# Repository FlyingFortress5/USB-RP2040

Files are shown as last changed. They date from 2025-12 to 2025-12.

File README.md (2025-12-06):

# USB-RP2040-DEVB
A RP2040 powered mini dev board. It has 2 GPIO pins, and is intended mainly for scripted HID emulation.

## Features

 - Light BOM
 - extra small size
 - male usb-c plug

## BOM

| Footprint | Designation | Quantity | | |
|---|---|---|---|---|
| USB_C_Plug_Molex_105444 | USB_C_Plug_USB2.0 | 1 | | |
| C_0402_1005Metric | 0.1uF | 10 | | |
| Winbond_USON-8-1EP_3x2mm_P0.5mm_EP0.2x1.6mm | W25Q16JVZPIQ_TR | 1 | | |
| SOT95P237X112-3N | MCP1700T-3302E_TT | 1 | | |
| SW_Push_1P1T-SH_NO_CK_KMR2xxG | SW_Push | 1 | | |
| PinHeader_1x03_P1.00mm_Vertical | Conn_01x03 | 1 | | |
| Crystal_SMD_3225-4Pin_3.2x2.5mm | 12 MHz | 1 | | |
| QFN-56-1EP_7x7mm_P0.4mm_EP3.2x3.2mm | RP2040 | 1 | | |
| R_0402_1005Metric | 10K | 1 | | |
| R_0402_1005Metric | 1K | 2 | | |
| R_0402_1005Metric | 27 | 2 | | |
| R_0402_1005Metric | 5.1K | 2 | | |
| C_0402_1005Metric | 15pF | 2 | | |
| C_0603_1608Metric_Pad1.08x0.95mm_HandSolder | 10uF | 2 | | |
| C_0402_1005Metric | 1uF | 2 | | |

## Case
A simple friction fit case

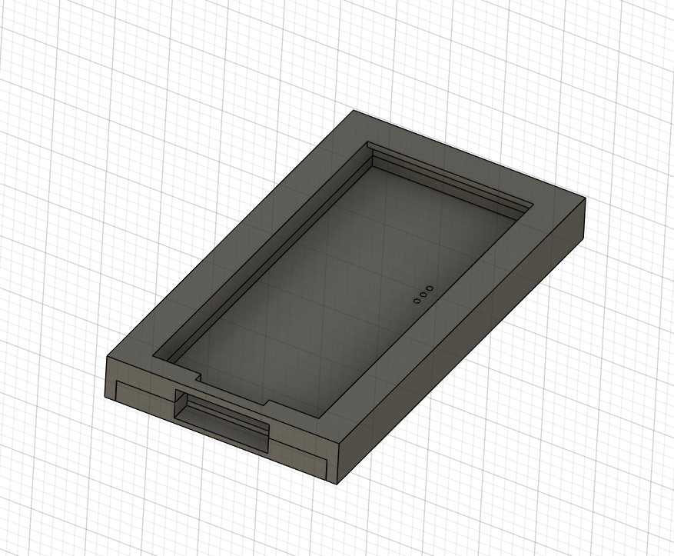
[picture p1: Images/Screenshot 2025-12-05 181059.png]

## Images

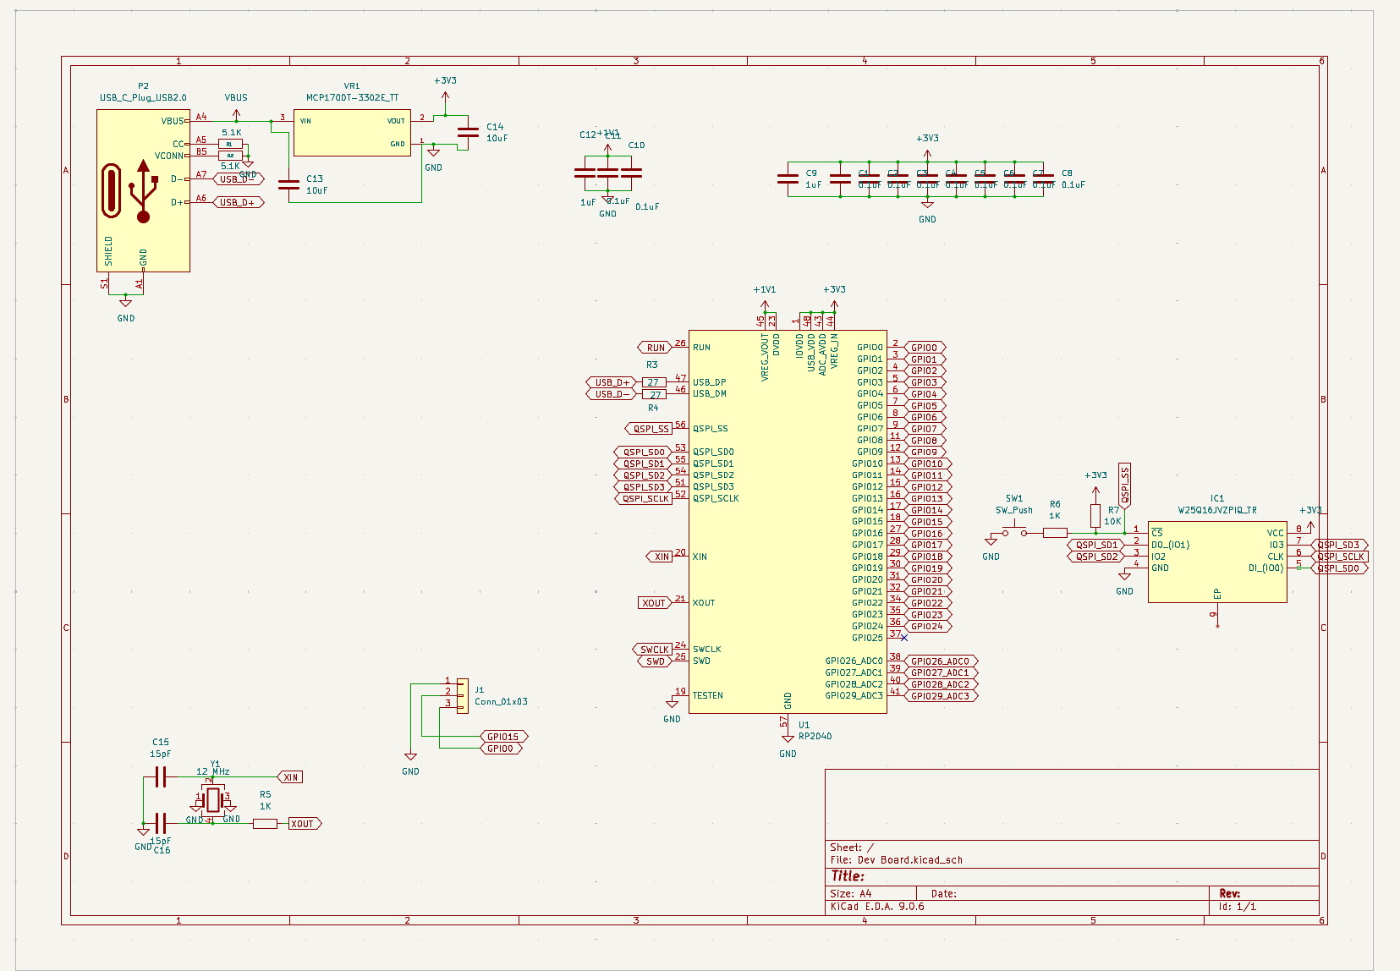
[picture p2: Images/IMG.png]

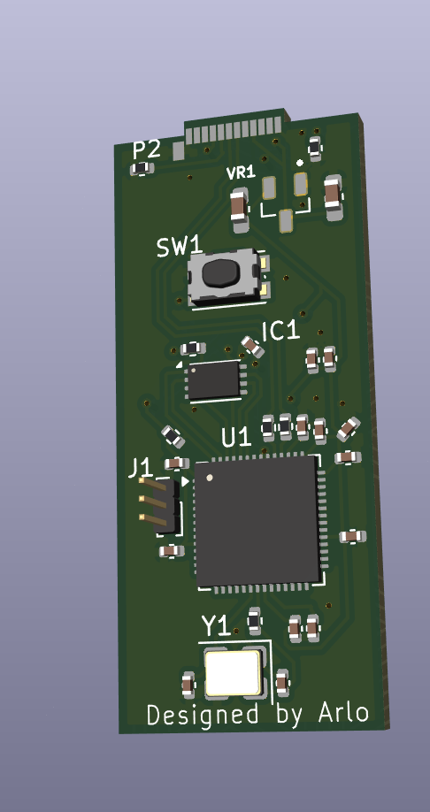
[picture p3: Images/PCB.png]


## Pinout

The pins on the header from top to bottom are:
 - GPIO0
 - GPIO15
 - GND
 The button enters BOOTSEL

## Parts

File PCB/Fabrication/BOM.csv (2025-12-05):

Id | Designator | Footprint | Quantity | Designation | Supplier and ref
1 | P2 | USB_C_Plug_Molex_105444 | 1 | USB_C_Plug_USB2.0
2 | C10,C11,C8,C7,C6,C5,C4,C3,C2,C1 | C_0402_1005Metric | 10 | 0.1uF
3 | IC1 | Winbond_USON-8-1EP_3x2mm_P0.5mm_EP0.2x1.6mm | 1 | W25Q16JVZPIQ_TR
4 | VR1 | SOT95P237X112-3N | 1 | MCP1700T-3302E_TT
5 | SW1 | SW_Push_1P1T-SH_NO_CK_KMR2xxG | 1 | SW_Push
6 | J1 | PinHeader_1x03_P1.00mm_Vertical | 1 | Conn_01x03
7 | Y1 | Crystal_SMD_3225-4Pin_3.2x2.5mm | 1 | 12 MHz
8 | U1 | QFN-56-1EP_7x7mm_P0.4mm_EP3.2x3.2mm | 1 | RP2040
9 | R7 | R_0402_1005Metric | 1 | 10K
10 | R6,R5 | R_0402_1005Metric | 2 | 1K
11 | R4,R3 | R_0402_1005Metric | 2 | 27
12 | R2,R1 | R_0402_1005Metric | 2 | 5.1K
13 | C16,C15 | C_0402_1005Metric | 2 | 15pF
14 | C14,C13 | C_0603_1608Metric_Pad1.08x0.95mm_HandSolder | 2 | 10uF
15 | C12,C9 | C_0402_1005Metric | 2 | 1uF

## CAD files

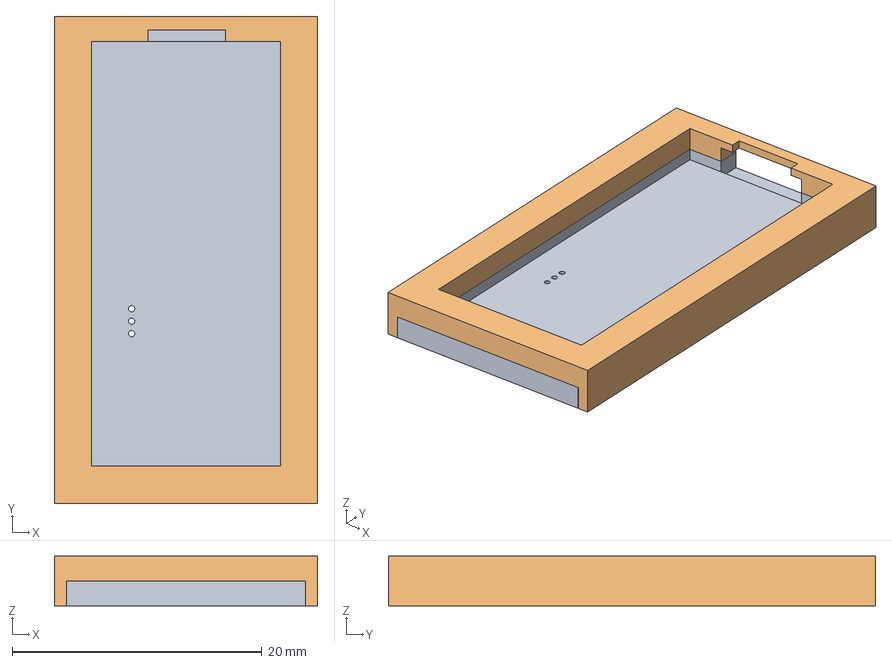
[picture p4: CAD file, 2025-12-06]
Case/Case.step
21.1 x 39.0 x 4.00 mm

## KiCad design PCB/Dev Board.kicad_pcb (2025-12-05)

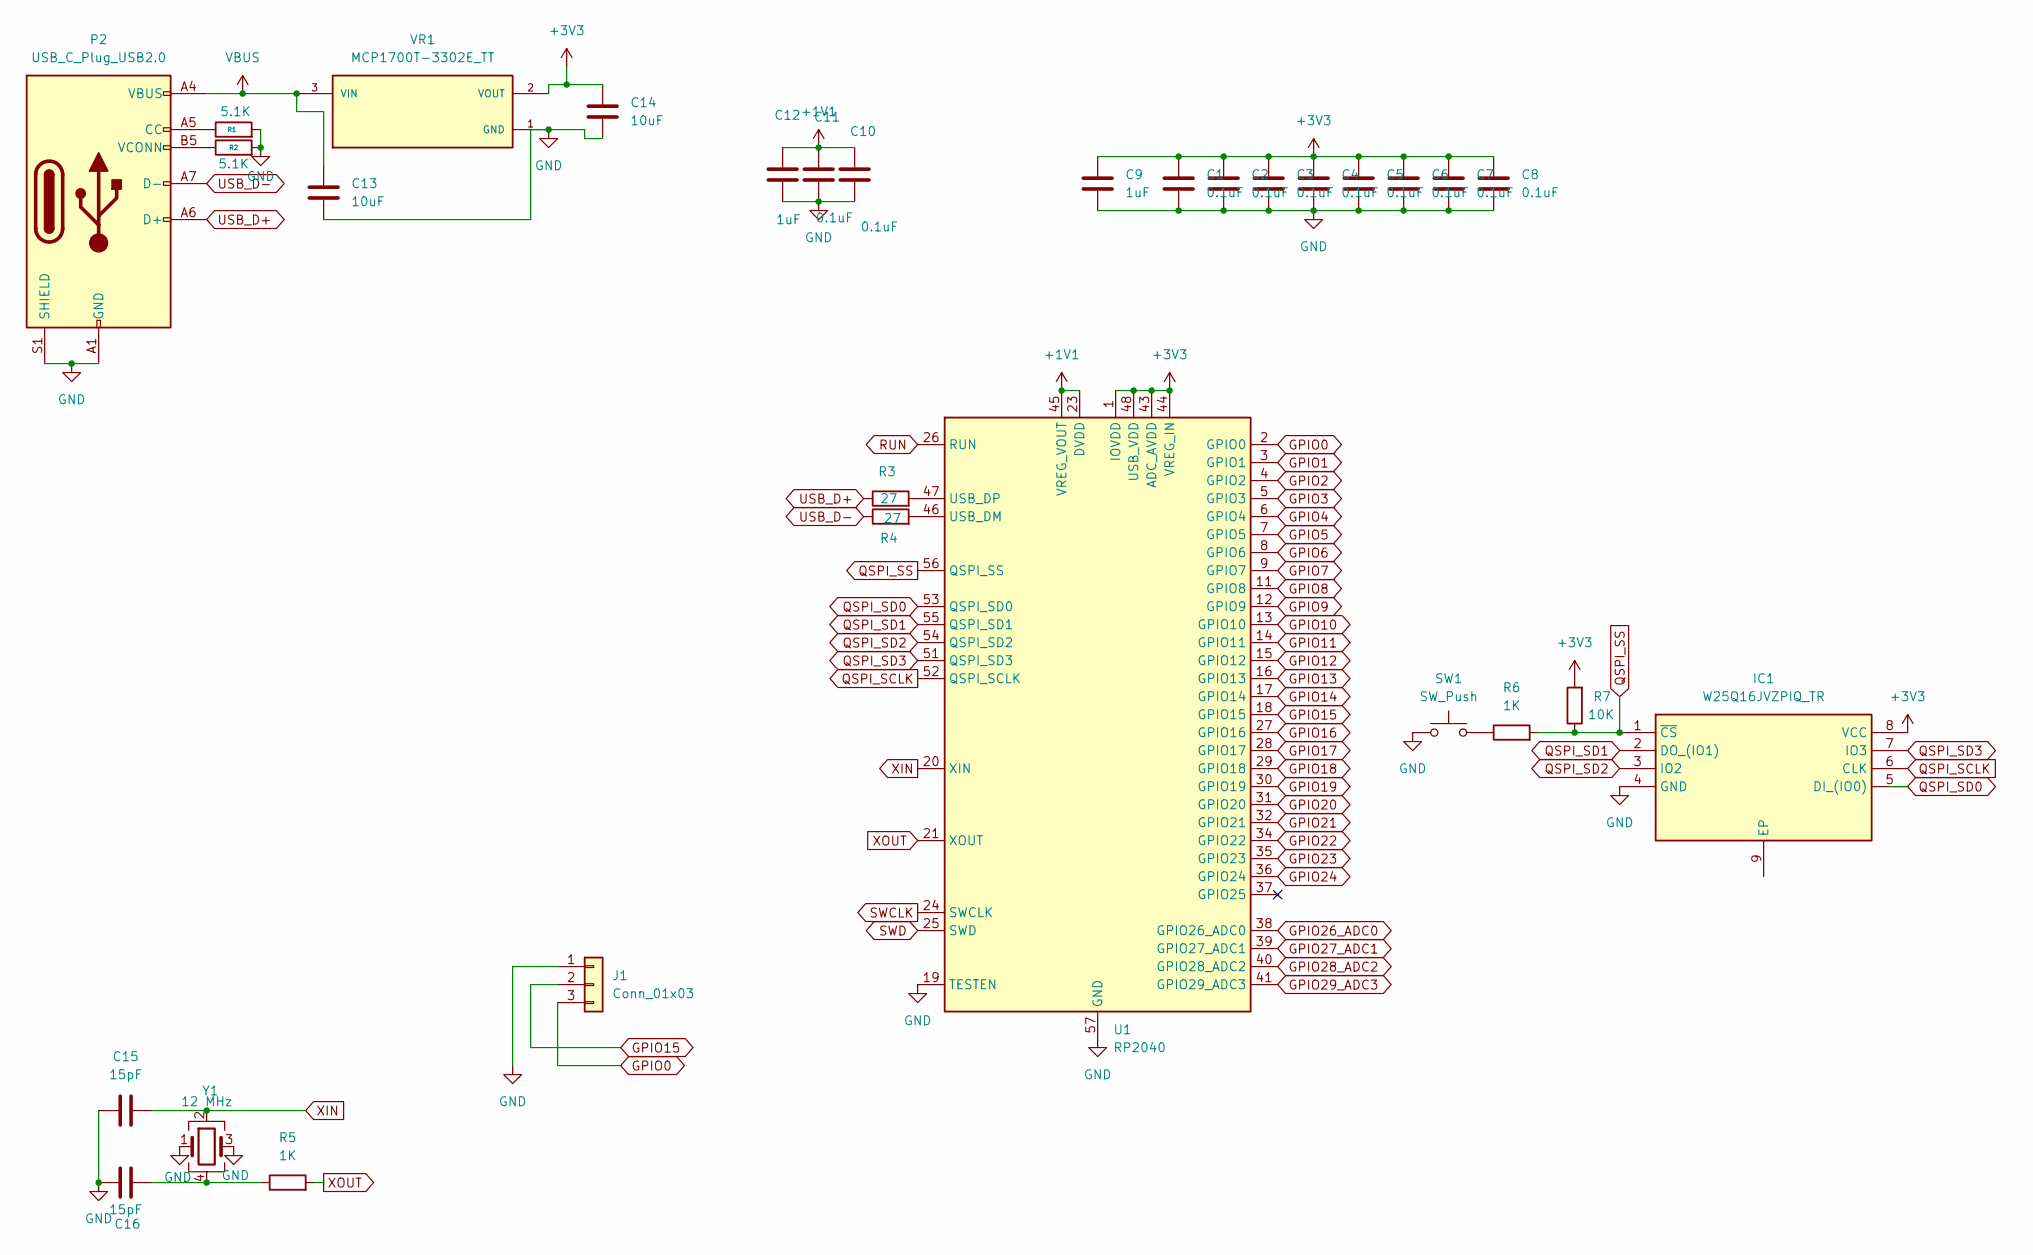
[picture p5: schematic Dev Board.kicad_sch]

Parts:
C1, C2, C3, C4, C5, C6, C7, C8, C10, C11: 0.1uF; C_0402_1005Metric
C9, C12: 1uF; C_0402_1005Metric
C13, C14: 10uF; C_0603_1608Metric_Pad1.08x0.95mm_HandSolder
C15, C16: 15pF; C_0402_1005Metric
IC1: W25Q16JVZPIQ_TR; Winbond_USON-8-1EP_3x2mm_P0.5mm_EP0.2x1.6mm; Manufacturer_Part_Number W25Q16JVZPIQ TR
J1: Conn_01x03; PinHeader_1x03_P1.00mm_Vertical
P2: USB_C_Plug_USB2.0; USB_C_Plug_Molex_105444
R1, R2: 5.1K; R_0402_1005Metric
R3, R4: 27; R_0402_1005Metric
R5, R6: 1K; R_0402_1005Metric
R7: 10K; R_0402_1005Metric
SW1: SW_Push; SW_Push_1P1T-SH_NO_CK_KMR2xxG
U1: RP2040; QFN-56-1EP_7x7mm_P0.4mm_EP3.2x3.2mm
VR1: MCP1700T-3302E_TT; SOT95P237X112-3N; PARTREV E
Y1: 12 MHz; Crystal_SMD_3225-4Pin_3.2x2.5mm

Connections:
+1V1: C10.1, C11.1, C12.1, U1.23 (DVDD), U1.45 (VREG_VOUT), U1.50 (DVDD)
+3V3: C1.1, C2.1, C3.1, C4.1, C5.1, C6.1, C7.1, C8.1, C9.1, C14.1, IC1.8 (VCC), R7.2, U1.1 (IOVDD), U1.10 (IOVDD), U1.22 (IOVDD), U1.33 (IOVDD), U1.42 (IOVDD), U1.43 (ADC_AVDD), U1.44 (VREG_IN), U1.48 (USB_VDD), U1.49 (IOVDD), VR1.2 (VOUT)
GND: C1.2, C2.2, C3.2, C4.2, C5.2, C6.2, C7.2, C8.2, C9.2, C10.2, C11.2, C12.2, C13.2, C14.2, C15.1, C16.1, IC1.4 (GND), J1.1, P2.A1 (GND), P2.A12 (GND), P2.B1 (GND), P2.B12 (GND), P2.S1 (SHIELD), R1.2, R2.2, SW1.1, U1.19 (TESTEN), U1.57 (GND), VR1.1 (GND), Y1.1, Y1.3
GPIO0: J1.3, U1.2 (GPIO0)
GPIO1: U1.3 (GPIO1)
GPIO2: U1.4 (GPIO2)
GPIO3: U1.5 (GPIO3)
GPIO4: U1.6 (GPIO4)
GPIO5: U1.7 (GPIO5)
GPIO6: U1.8 (GPIO6)
GPIO7: U1.9 (GPIO7)
GPIO8: U1.11 (GPIO8)
GPIO9: U1.12 (GPIO9)
GPIO10: U1.13 (GPIO10)
GPIO11: U1.14 (GPIO11)
GPIO12: U1.15 (GPIO12)
GPIO13: U1.16 (GPIO13)
GPIO14: U1.17 (GPIO14)
GPIO15: J1.2, U1.18 (GPIO15)
GPIO16: U1.27 (GPIO16)
GPIO17: U1.28 (GPIO17)
GPIO18: U1.29 (GPIO18)
GPIO19: U1.30 (GPIO19)
GPIO20: U1.31 (GPIO20)
GPIO21: U1.32 (GPIO21)
GPIO22: U1.34 (GPIO22)
GPIO23: U1.35 (GPIO23)
GPIO24: U1.36 (GPIO24)
GPIO26_ADC0: U1.38 (GPIO26_ADC0)
GPIO27_ADC1: U1.39 (GPIO27_ADC1)
GPIO28_ADC2: U1.40 (GPIO28_ADC2)
GPIO29_ADC3: U1.41 (GPIO29_ADC3)
unnamed: C16.2, R5.1, Y1.4
unnamed: P2.A5 (CC), R1.1
unnamed: P2.B5 (VCONN), R2.1
unnamed: R6.1, SW1.2
unnamed: R4.2, U1.46 (USB_DM)
unnamed: R3.2, U1.47 (USB_DP)
QSPI_SCLK: IC1.6 (CLK), U1.52 (QSPI_SCLK)
QSPI_SD0: IC1.5 (DI_(IO0)), U1.53 (QSPI_SD0)
QSPI_SD1: IC1.2 (DO_(IO1)), U1.55 (QSPI_SD1)
QSPI_SD2: IC1.3 (IO2), U1.54 (QSPI_SD2)
QSPI_SD3: IC1.7 (IO3), U1.51 (QSPI_SD3)
QSPI_SS: IC1.1 (~CS), R6.2, R7.1, U1.56 (QSPI_SS)
RUN: U1.26 (RUN)
SWCLK: U1.24 (SWCLK)
SWD: U1.25 (SWD)
USB_D+: P2.A6 (D+), R3.1
USB_D-: P2.A7 (D-), R4.1
VBUS: C13.1, P2.A4 (VBUS), P2.A9 (VBUS), P2.B4 (VBUS), P2.B9 (VBUS), VR1.3 (VIN)
XIN: C15.2, U1.20 (XIN), Y1.2
XOUT: R5.2, U1.21 (XOUT)

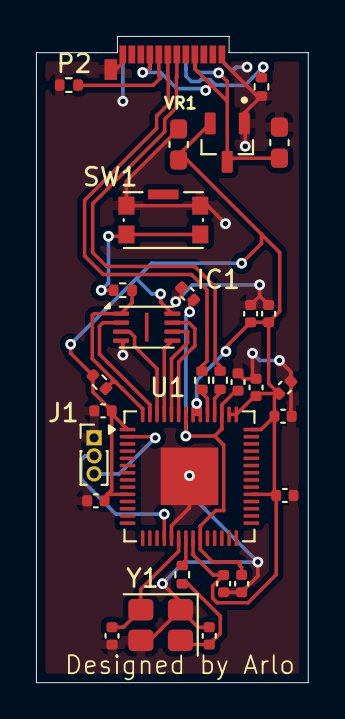
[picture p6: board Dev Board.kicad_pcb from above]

Board: 2 copper layers, 15.1 x 35.9 mm, 30 parts (0 on the bottom side), 22 nets.

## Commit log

2025-12-05 Edit Readme and add PCB files and images
    [Dev Board-B_Cu.gbr, Dev Board-B_Mask.gbr, Dev Board-B_Paste.gbr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]
2025-12-06 Added case
    [Case.step]
2025-12-06 Added gerber drill files
    [Dev Board-NPTH-drl.gbr, Dev Board-NPTH.drl, Dev Board-PTH-drl.gbr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]
2025-12-06 Rename Dev Board.csv to BOM.csv
    [BOM.csv]
